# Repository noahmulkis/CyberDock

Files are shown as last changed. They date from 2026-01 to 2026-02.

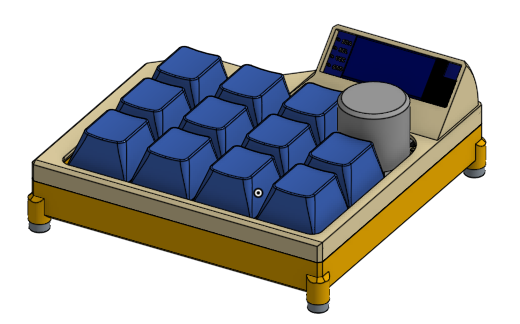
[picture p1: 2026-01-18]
README/Main.png

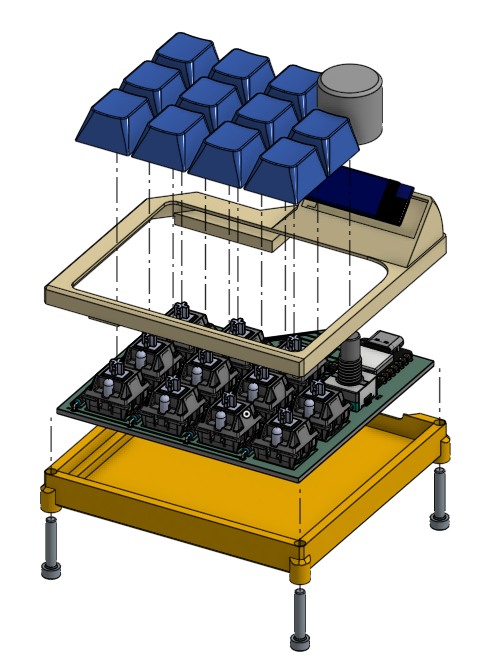
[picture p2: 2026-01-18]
README/Exploded.png

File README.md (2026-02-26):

<h1 align="center">CyberDock</h1>

<p align="center">
  Welcome to CyberDock, my custom 3D printed Macropad that runs KMK firmware.
</p>

<p align="center">
  Main
</p>

<p align="center">
  Exploded
</p>

<hr>

<h2>PCB and Schematic</h2>

<p align="center">
  PCB
</p>

<p align="center">
  Schematic
" />
</p>

<hr>

<h2>Bill of Materials:</h2>

<ul>
  <li>1x CyberDock PCB</li>
  <li>1x XIAO-PR2040-DIP</li>
  <li>1x EC11 rotary encoder</li>
  <li>11x Cherry MX (or equivalent) keyswitches</li>
  <li>11x Keycaps</li>
  <li>12x 1N4148 Throughhole diodes</li>
  <li>1x 0.91 inch OLED display (SSD1306 I2C 0.91 128x32)</li>
  <li>4x Cap head M3x16 machine screws</li>
  <li>1x 3D printed shell top half</li>
  <li>1x 3D printed shell bottom half</li>
</ul>

<p>
  small amount of spare wire apprx. 50mm worth.
</p>

<hr>

<h2>Instructions for Assembly:</h2>

<ol>
  <li>Solder RP2040 directly onto the pcb without a header.</li>
  <li>Solder on Diodes aligning with the slikscreen.</li>
  <li>Solder CherryMX switches to board.</li>
  <li>
    Solder breakout cables to the spare 4 pins near the RP2040, these will be used to wire to the OLED display.
    Make these breakout cables ~2" to allow for easier soledering.
  </li>
  <li>
    Clamshell the base around the PCB, passing the breakout cables through the small hole in the gap for the display
    in the top half of the case, then use the M3x16 machine screws to clamp the assembly together.
  </li>

  <li>Solder display to the breakout cables</li>
  <li>Use double-sided tape or a light adhesive to hold the OLED into its holder,.</li>

</ol>
 


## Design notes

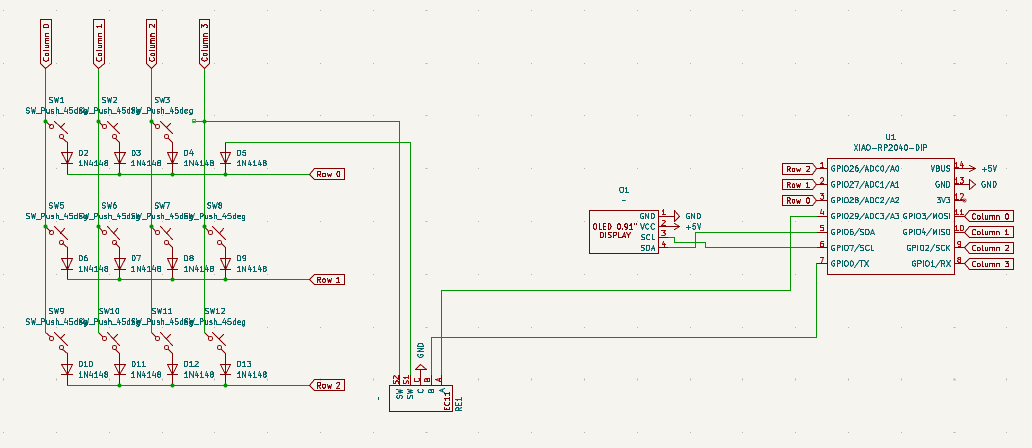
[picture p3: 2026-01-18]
README/Schematic.png

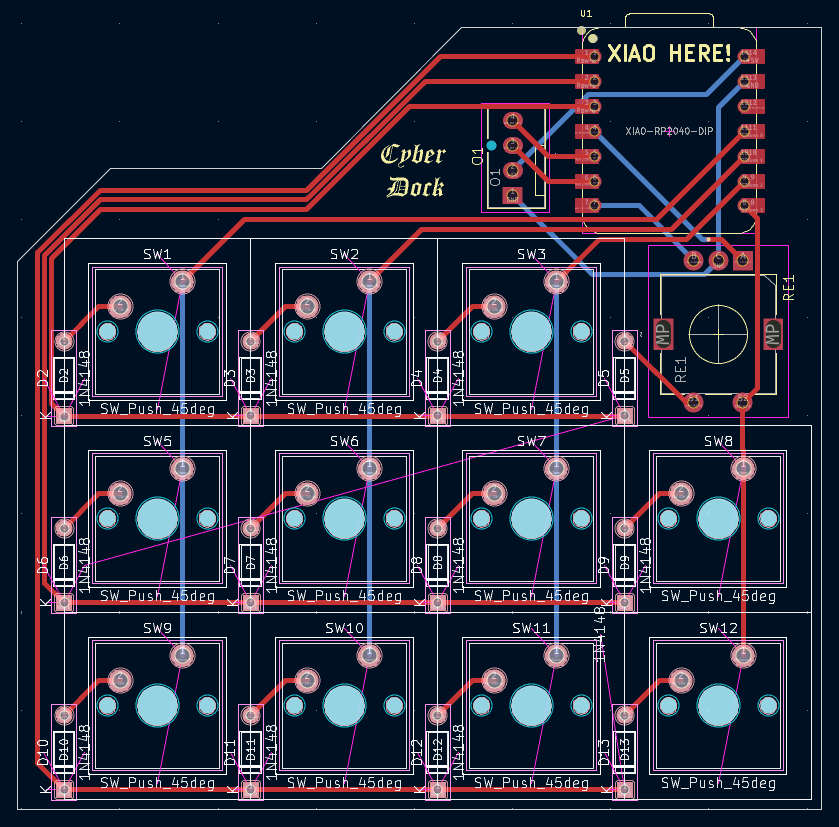
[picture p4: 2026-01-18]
README/PCB.png

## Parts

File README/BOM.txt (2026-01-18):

Bill of Materials:
1x CyberDock PCB
1x XIAO-PR2040-DIP
1x EC11 rotary encoder
11x Cherry MX (or equivalent) keyswitches
11x Keycaps
12x 1N4148 Throughhole diodes
1x 0.91 inch OLED display (SSD1306 I2C 0.91 128x32)
4x Cap head M3x16 machine screws
1x 3D printed shell top half
1x 3D printed shell bottom half

small amount of spare wire apprx. 50mm worth.

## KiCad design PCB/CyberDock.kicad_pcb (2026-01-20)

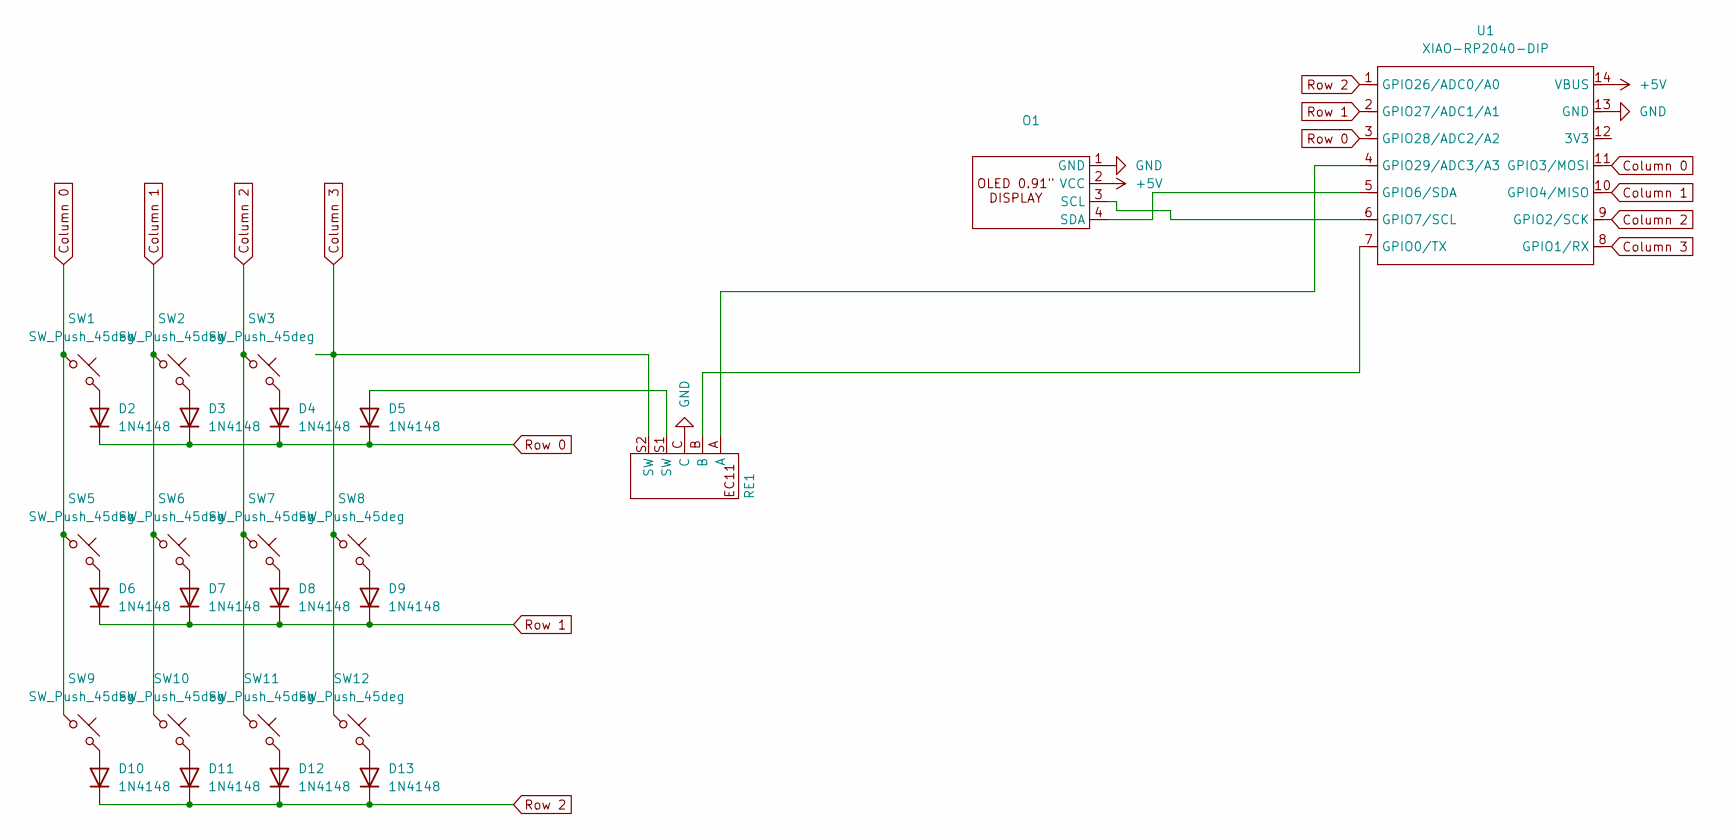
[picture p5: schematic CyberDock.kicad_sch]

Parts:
D2, D3, D4, D5, D6, D7, D8, D9, D10, D11, D12, D13: 1N4148; D_DO-35_SOD27_P7.62mm_Horizontal
O1: FanPinHeader_1x04_P2.54mm_Vertical
RE1: RotaryEncoder_Alps_EC11E-Switch_Vertical_H20mm
SW1, SW2, SW3, SW5, SW6, SW7, SW8, SW9, SW10, SW11, SW12: SW_Push_45deg; SW_Cherry_MX_1.00u_PCB
U1: XIAO-RP2040-DIP

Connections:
+5V: O1.2 (VCC), U1.14 (VBUS)
Column 0: SW1.1, SW5.1, SW9.1, U1.11 (GPIO3/MOSI)
Column 1: SW2.1, SW6.1, SW10.1, U1.10 (GPIO4/MISO)
Column 2: SW3.1, SW7.1, SW11.1, U1.9 (GPIO2/SCK)
Column 3: RE1.S2 (SW), SW8.1, SW12.1, U1.8 (GPIO1/RX)
GND: O1.1 (GND), RE1.C, U1.13 (GND)
unnamed: D2.2 (A), SW1.2
unnamed: D3.2 (A), SW2.2
unnamed: D4.2 (A), SW3.2
unnamed: D5.2 (A), RE1.S1 (SW)
unnamed: D6.2 (A), SW5.2
unnamed: D7.2 (A), SW6.2
unnamed: D8.2 (A), SW7.2
unnamed: D9.2 (A), SW8.2
unnamed: D10.2 (A), SW9.2
unnamed: D11.2 (A), SW10.2
unnamed: D12.2 (A), SW11.2
unnamed: D13.2 (A), SW12.2
unnamed: O1.3 (SCL), U1.6 (GPIO7/SCL)
unnamed: O1.4 (SDA), U1.5 (GPIO6/SDA)
unnamed: RE1.B, U1.7 (GPIO0/TX)
unnamed: RE1.A, U1.4 (GPIO29/ADC3/A3)
Row 0: D2.1 (K), D3.1 (K), D4.1 (K), D5.1 (K), U1.3 (GPIO28/ADC2/A2)
Row 1: D6.1 (K), D7.1 (K), D8.1 (K), D9.1 (K), U1.2 (GPIO27/ADC1/A1)
Row 2: D10.1 (K), D11.1 (K), D12.1 (K), D13.1 (K), U1.1 (GPIO26/ADC0/A0)

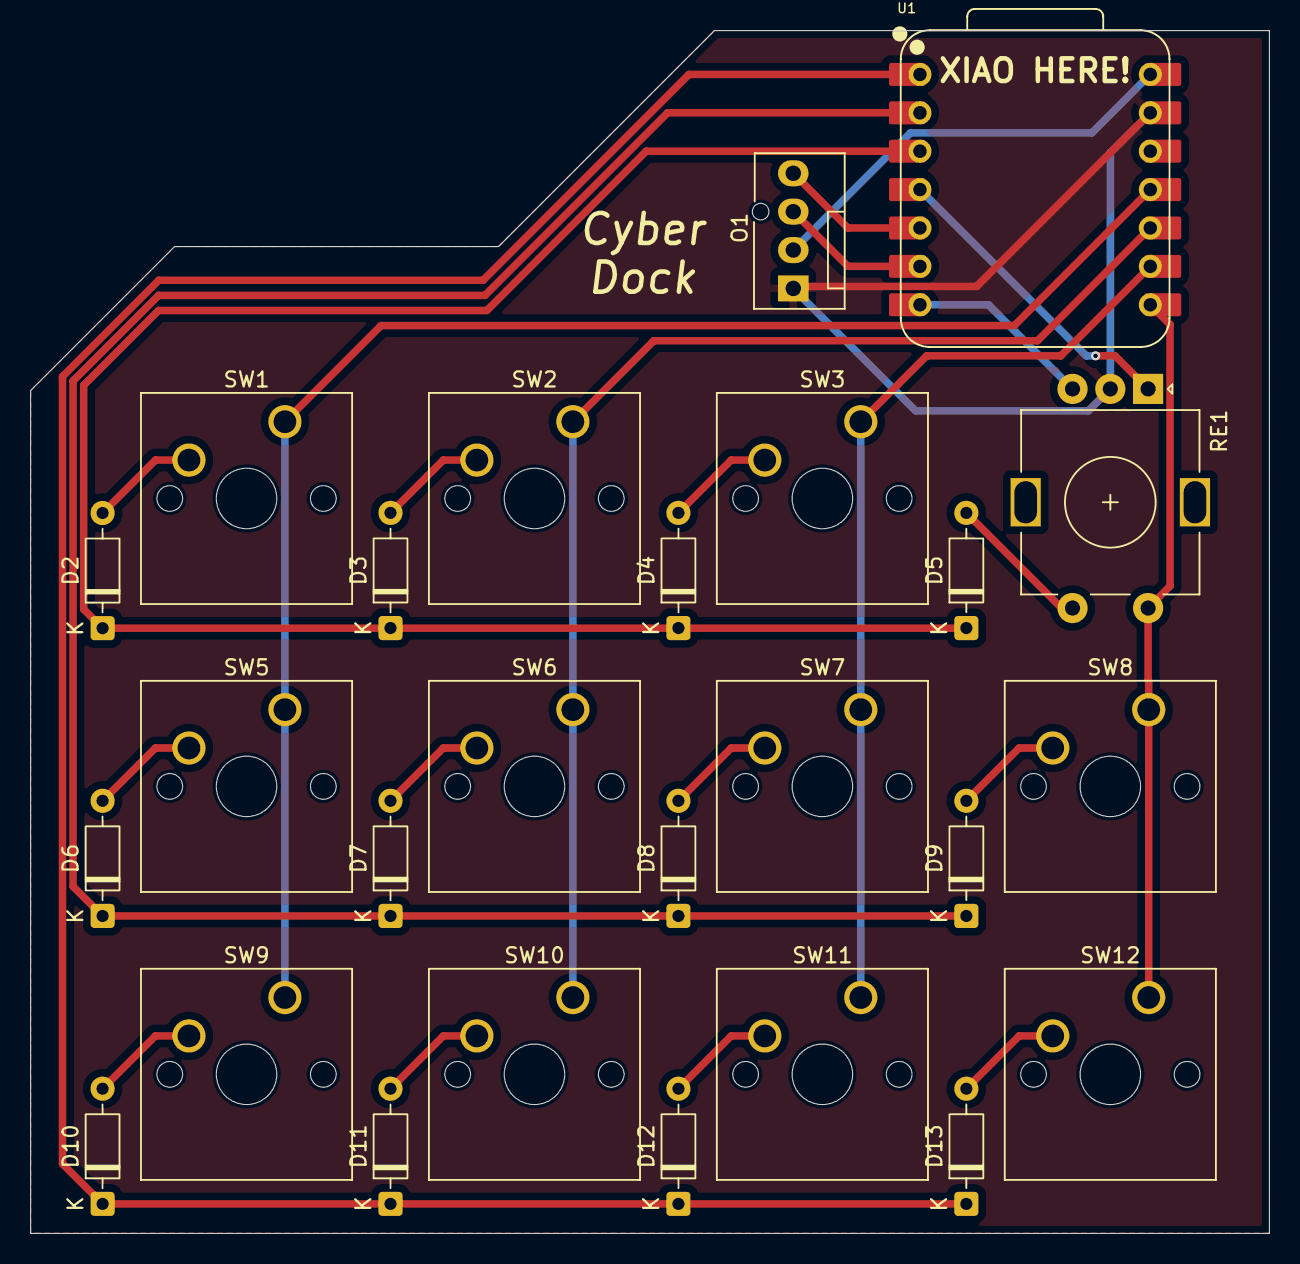
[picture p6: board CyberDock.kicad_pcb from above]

Board: 2 copper layers, 82.0 x 79.6 mm, 26 parts (0 on the bottom side), 25 nets.

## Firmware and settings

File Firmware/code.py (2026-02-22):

print("Starting")
import board
import busio
import digitalio
import time
from kmk.kmk_keyboard import KMKKeyboard
from kmk.keys import KC
from kmk.scanners import DiodeOrientation
from kmk.extensions.media_keys import MediaKeys
from kmk.modules.layers import Layers
import adafruit_ssd1306

# --- OLED Setup ---
i2c = busio.I2C(board.D5, board.D4)
oled = adafruit_ssd1306.SSD1306_I2C(128, 32, i2c)

# --- Layer Names ---
LAYER_NAMES = ["Main", "Onshape", "Reaper"]
current_layer = 0

# --- Key Labels per layer ---
LAYER_LABELS = [
    [
        ["PREV", "NEXT", "PLAY", "LYR"],
        ["SNIP", "SHOW", "LOCK", "EMOJI"],
        ["RUN",  "TABS", "MUTE", "DESK"],
    ],
    [
        ["SKTCH", "EXVW", "FIT",  "LYR"],
        ["FRONT", "RGHT", "TOP",  "MATE"],
        ["ZOOM+", "ZOOM-","ROT",  "LYR"],
    ],
    [
        ["PLAY", "STOP", "REC",  "LYR"],
        ["MUTE", "SOLO", "LOOP", "QTSE"],
        ["ZM+",  "ZM-",  "TAP",  "LYR"],
    ],
]

# --- Key Actions per layer ---
LAYER_ACTIONS = [
    [
        "Prev Track", "Next Track", "Play/Pause", "Next Layer",
        "Snip", "Show Desktop", "Lock", "Emoji",
        "Run", "Task View", "Mute", "New Desktop",
    ],
    [
        "Sketch", "Exit View", "Fit All", "Next Layer",
        "Front View", "Right View", "Top View", "Mate",
        "Zoom In", "Zoom Out", "Rotate", "Next Layer",
    ],
    [
        "Play", "Stop", "Record", "Next Layer",
        "Mute Track", "Solo Track", "Toggle Loop", "Quantise",
        "Zoom In", "Zoom Out", "Tap Tempo", "Next Layer",
    ],
]

TIMEOUT = 1
DISPLAY_INTERVAL = 0.5

last_action_time = None
last_display_update = 0
pending_action = None
pending_is_volume = False
volume_direction = None

def draw_static():
    oled.fill(0)
    layer_label = LAYER_NAMES[current_layer]
    oled.text(layer_label, 0, 0, 1)
    oled.fill_rect(0, 9, 128, 1, 1)
    labels = LAYER_LABELS[current_layer]
    for row in range(3):
        for col in range(4):
            x = col * 32
            y = 11 + row * 7
            oled.text(labels[row][col], x, y, 1)
    oled.show()

def show_action(label):
    global last_action_time
    oled.fill(0)
    char_width = 12
    text_width = len(label) * char_width
    x = max(0, (128 - text_width) // 2)
    y = 8
    oled.text(label, x, y, 1, size=2)
    oled.show()
    last_action_time = time.monotonic()

def show_volume(direction):
    oled.fill(0)
    label = "Vol Up" if direction == "up" else "Vol Down"
    char_width = 12
    text_width = len(label) * char_width
    x = max(0, (128 - text_width) // 2)
    y = 8
    oled.text(label, x, y, 1, size=2)
    oled.show()

def show_layer_name(name):
    oled.fill(0)
    char_w = 12
    text_w = len(name) * char_w
    x = max(0, (128 - text_w) // 2)
    oled.text(name, x, 8, 1, size=2)
    oled.show()

draw_static()

# --- Keyboard Setup ---
keyboard = KMKKeyboard()
keyboard.col_pins = (board.D10, board.D9, board.D8, board.D7)
keyboard.row_pins = (board.D2, board.D1, board.D0)
keyboard.diode_orientation = DiodeOrientation.COL2ROW
keyboard.extensions.append(MediaKeys())

layers_mod = Layers()
keyboard.modules.append(layers_mod)

LYR_MAIN    = KC.TO(0)
LYR_ONSHAPE = KC.TO(1)
LYR_REAPER  = KC.TO(2)

keyboard.keymap = [
    # Layer 0 - Main
    [
        KC.MPRV,                    KC.MNXT,           KC.MPLY,                 LYR_ONSHAPE,
        KC.LGUI(KC.LSFT(KC.S)),     KC.LGUI(KC.D),     KC.LGUI(KC.L),           KC.LGUI(KC.DOT),
        KC.LGUI(KC.R),              KC.LGUI(KC.TAB),   KC.MUTE,                 KC.LCTL(KC.LGUI(KC.D)),
    ],
    # Layer 1 - Onshape
    [
        KC.S,                       KC.E,              KC.F,                    LYR_REAPER,
        KC.LCTL(KC.NUM_1),          KC.LCTL(KC.NUM_2), KC.LCTL(KC.NUM_3),       KC.M,
        KC.LCTL(KC.EQUAL),          KC.LCTL(KC.MINUS), KC.LCTL(KC.R),           LYR_REAPER,
    ],
    # Layer 2 - Reaper
    [
        KC.SPACE,                   KC.LCTL(KC.SPACE), KC.LCTL(KC.LSFT(KC.R)), LYR_MAIN,
        KC.F6,                      KC.F8,             KC.LCTL(KC.L),           KC.LCTL(KC.LSFT(KC.Q)),
        KC.LCTL(KC.EQUAL),          KC.LCTL(KC.MINUS), KC.LALT(KC.LSFT(KC.T)), LYR_MAIN,
    ],
]

# --- Encoder Setup ---
clk = digitalio.DigitalInOut(board.D3)
clk.direction = digitalio.Direction.INPUT
clk.pull = digitalio.Pull.UP

dt = digitalio.DigitalInOut(board.D6)
dt.direction = digitalio.Direction.INPUT
dt.pull = digitalio.Pull.UP

ENCODER_TABLE = {
    (1, 1, 0, 1): -1,
    (0, 1, 0, 0): -1,
    (0, 0, 1, 0): -1,
    (1, 0, 1, 1): -1,
    (1, 1, 1, 0): +1,
    (1, 0, 0, 0): +1,
    (0, 0, 0, 1): +1,
    (0, 1, 1, 1): +1,
}

last_clk = int(clk.value)
last_dt = int(dt.value)
accumulated = 0

_original_main_loop = keyboard._main_loop
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

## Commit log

2026-01-20 Update schematic image link in README.md
2026-02-26 Update assembly instructions in README
